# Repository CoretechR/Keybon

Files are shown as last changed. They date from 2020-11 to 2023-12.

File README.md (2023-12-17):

# Keybon - Adaptive Macro Keyboard

Keybon is a macro keyboard with configurable layouts and functions. Integrated into each of its nine tactile buttons is a 0.66” OLED screen. Depending on which app is active on the connected computer, Keybon switches to the suitable key layout thanks to its companion software.

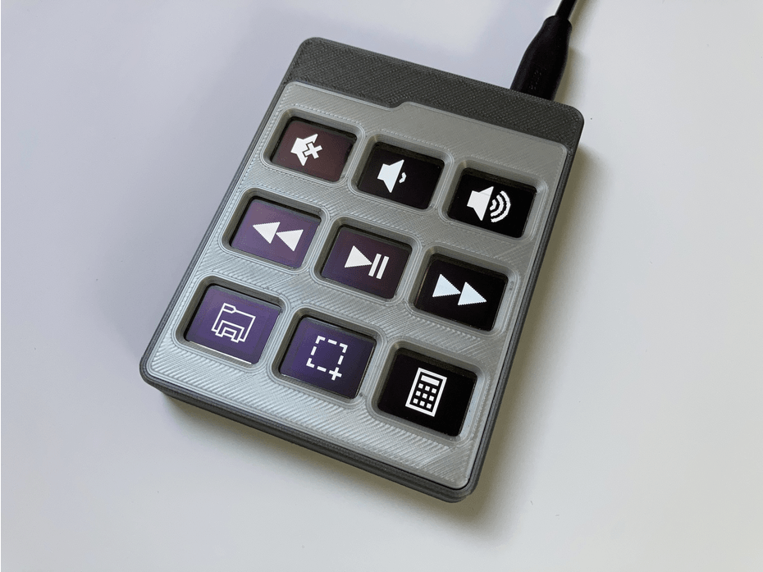
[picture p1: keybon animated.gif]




# Instructions

1.  Download the USB bootloader: https://github.com/rogerclarkmelbourne/STM32duino-bootloader

    Connect a USB-to-Serial adapter to the TX/RX pins of your board. Close the BOOT0 jumper before applying power.
    
    Flash the USB bootloader to the STM32 via the STM32 flasher:  https://www.st.com/en/development-tools/flasher-stm32.html
2.  Install the required Arduino libraries listed in the keybon.ino file

    Important: Adafruit_GFX_Library version 1.7.5 must be installed (dependencies for newer versions are incompatible with the STM32)
    
    Add the following lines to the Adafruit_SSD1306 library (in Arduino\libraries\Adafruit_SSD1306\Adafruit_SSD1306.cpp) 
    
    ```C++
    else if ((WIDTH == 128) && (HEIGHT == 48)) {
    comPins = 0x12;
	  contrast = (vccstate == SSD1306_EXTERNALVCC) ? 0x9F : 0xCF;
    }
    ```
3.  Install STM32 support for the Arduino IDE: https://github.com/rogerclarkmelbourne/Arduino_STM32

    Install the corresponding drivers: https://github.com/rogerclarkmelbourne/Arduino_STM32/tree/master/drivers
4.  Compile and upload the Arduino sketch:



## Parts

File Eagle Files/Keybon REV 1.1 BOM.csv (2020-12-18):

Qty | Value | Device | Package | Parts | LCSC Link
1 |  | USB_C16PIN | USB-C-16P | J2 | https://lcsc.com/product-detail/USB-Connectors_SOFNG-MC-311D_C136423.html
32 | 1.0uF |  | 0603 | C1; C2; C3; C8; C10; C11; C14; C15; C18; C19; C20; C23; C24; C25; C28; C29; C30; C33; C34; C35; C38; C39; C40; C43; C44; C45; C48; C49; C50; C53; C54; C55 | https://lcsc.com/product-detail/Multilayer-Ceramic-Capacitors-MLCC-SMD-SMT_Samsung-Electro-Mechanics-CL10A105MB8NNNC_C307457.html
3 | 10k |  | 0603 | R8; R12; R15 | https://lcsc.com/product-detail/Chip-Resistor-Surface-Mount_10KR-103-5_C144116.html
2 | 18pF |  | 0603 | C6; C7 | https://lcsc.com/product-detail/Multilayer-Ceramic-Capacitors-MLCC-SMD-SMT_Walsin-Tech-Corp-0603N180J500CT_C123538.html
3 | 1k |  | 0603 | R16; R17; R18 | https://lcsc.com/product-detail/Chip-Resistor-Surface-Mount_FH-Guangdong-Fenghua-Advanced-Tech-RS-03K1001FT_C115325.html
1 | 1k5 |  | 0603 | R20 | https://lcsc.com/product-detail/Chip-Resistor-Surface-Mount_1-5KR-152-5_C138275.html
10 | 2.2uF |  | 0603 | C4; C9; C17; C22; C27; C32; C37; C42; C47; C52 | https://lcsc.com/product-detail/Multilayer-Ceramic-Capacitors-MLCC-SMD-SMT_YAGEO-CC0603MRY5V7BB225_C519506.html
2 | 27 |  | 0603 | R13; R14 | https://lcsc.com/product-detail/Chip-Resistor-Surface-Mount_TA-I-Tech-RMS06JT270_C209231.html
9 | 390k |  | 0603 | R1; R2; R4; R5; R6; R7; R9; R10; R11 | https://lcsc.com/product-detail/Chip-Resistor-Surface-Mount_YAGEO-RC0603JR-07390KL_C137633.html
9 | 4.7uF |  | 0603 | C5; C16; C21; C26; C31; C36; C41; C46; C51 | https://lcsc.com/product-detail/Multilayer-Ceramic-Capacitors-MLCC-SMD-SMT_YAGEO-CC0805KKX7R6BB475_C520074.html
2 | 47pF |  | 0603 | C12; C13 | https://lcsc.com/product-detail/Multilayer-Ceramic-Capacitors-MLCC-SMD-SMT_YAGEO-CC0603JRNPO8BN470_C519392.html
2 | 5.1k |  | 0603 | R3; R19 | https://lcsc.com/product-detail/Chip-Resistor-Surface-Mount_RALEC-RTT035101FTP_C103686.html
1 | 500mA | PTCSMD | PTC-1206 | F1 | https://lcsc.com/product-detail/PTC-Resettable-Fuses_Fuzetec-Tech-FSMD025-24-1206-R_C220146.html
1 | 8MHz | CRYSTAL5X3 | CRYSTAL-SMD-5X3 | OSC | https://lcsc.com/product-detail/SMD-Crystal-Resonators_Abracon-LLC-ABM3B-8-000MHZ-10-1-U-T_C276420.html
1 | AP2112K-3.3V | V_REG_LDOSMD | SOT23-5 | U3 | https://lcsc.com/product-detail/Dropout-Regulators-LDO_Diodes-Incorporated_AP2112K-3-3TRG1_Diodes-Incorporated-AP2112K-3-3TRG1_C51118.html
10 | EVQQ | B3FS-1000P | EVQ-Q2_SMALLER | SW1; SW2; SW3; SW4; SW5; SW6; SW7; SW8; SW9; SW10 | https://lcsc.com/product-detail/Tactile-Switches_Omron-Electronics-B3FS-1000P_C271750.html
9 | OLED0.66 | OLED0.66 | OLED-0.66-64X48 | OLED1; OLED2; OLED3; OLED4; OLED5; OLED6; OLED7; OLED8; OLED9 | https://lcsc.com/product-detail/OLED-Displays-Modules_UG-Univision-Semicon-UG-6448KLBEG03_C88334.html
1 | STM32F103C8T6 | STM32F103C8T6 | LQFP48 | UC1 | https://lcsc.com/product-detail/ST-Microelectronics_STMicroelectronics-STM32F103C8T6_C8734.html

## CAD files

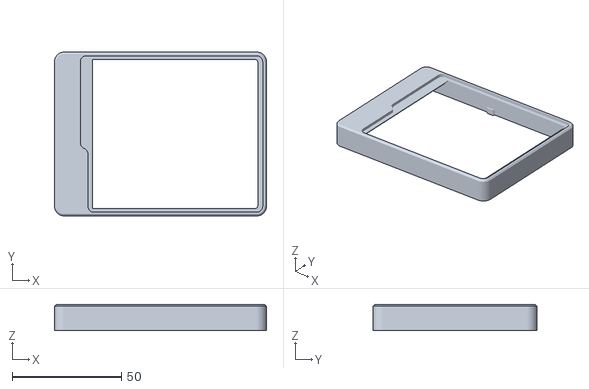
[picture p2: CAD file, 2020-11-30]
CAD Files/Shell.stl
97.0 x 75.0 x 12.0

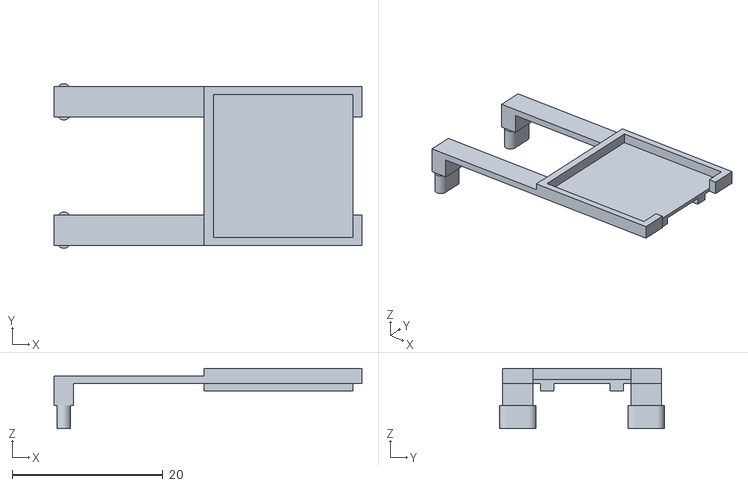
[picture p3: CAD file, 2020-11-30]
CAD Files/button A.stl
40.8 x 21.8 x 8.00

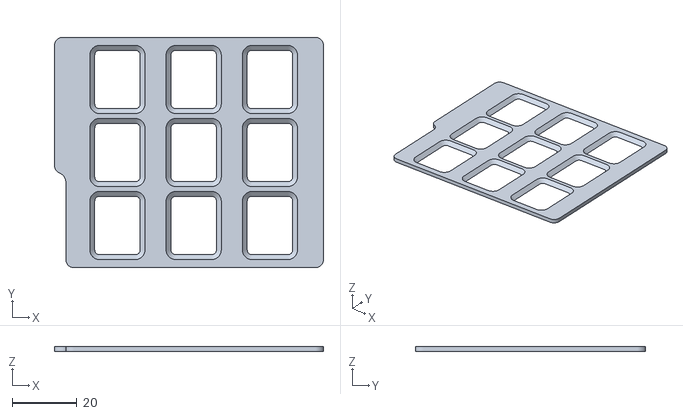
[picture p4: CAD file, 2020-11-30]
CAD Files/Cover Plate.stl
82.9 x 71.0 x 1.50

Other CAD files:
CAD Files/button B.stl

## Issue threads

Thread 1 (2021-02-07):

Unable to build the firmware

r00li, 2021-02-07:
Hi!
I managed to assemble the hardware for this and I am now trying to get the firmware built but I am not having any luck. Can you provide a bit more information on the versions of the libraries that were used? Or maybe even provide a pre-built bin file that can be flashed onto the board?

I've downloaded the latest versions of the Arduino_STM32 that was linked on the hackaday project, I am also using the latest versions of other libraries that are used and I am getting the following errors when I am trying to compile the firmware source:

```WARNING: library JC_Button-2.1.2 claims to run on avr architecture(s) and may be incompatible with your current board which runs on STM32F1 architecture(s).
/Users/roli/Documents/Arduino/libraries/Adafruit_BusIO/Adafruit_I2CDevice.cpp: In member function 'bool Adafruit_I2CDevice::write(const uint8_t*, size_t, bool, const uint8_t*, size_t)':
/Users/roli/Documents/Arduino/libraries/Adafruit_BusIO/Adafruit_I2CDevice.cpp:88:47: error: invalid conversion from 'const uint8_t* {aka const unsigned char*}' to 'uint8* {aka unsigned char*}' [-fpermissive]
     if (_wire->write(prefix_buffer, prefix_len) != prefix_len) {
                                               ^
In file included from /Users/roli/Documents/Arduino/hardware/Arduino_STM32/STM32F1/libraries/Wire/Wire.h:42:0,
                 from /Users/roli/Documents/Arduino/libraries/Adafruit_BusIO/Adafruit_I2CDevice.h:1,
                 from /Users/roli/Documents/Arduino/libraries/Adafruit_BusIO/Adafruit_I2CDevice.cpp:1:
/Users/roli/Documents/Arduino/hardware/Arduino_STM32/STM32F1/libraries/Wire/utility/WireBase.h:123:12: note:   initializing argument 1 of 'size_t WireBase::write(uint8*, int)'
     size_t write(uint8*, int);
            ^~~~~
/Users/roli/Documents/Arduino/libraries/Adafruit_BusIO/Adafruit_I2CDevice.cpp:97:31: error: invalid conversion from 'const uint8_t* {aka const unsigned char*}' to 'uint8* {aka unsigned char*}' [-fpermissive]
   if (_wire->write(buffer, len) != len) {
                               ^
In file included from /Users/roli/Documents/Arduino/hardware/Arduino_STM32/STM32F1/libraries/Wire/Wire.h:42:0,
                 from /Users/roli/Documents/Arduino/libraries/Adafruit_BusIO/Adafruit_I2CDevice.h:1,
                 from /Users/roli/Documents/Arduino/libraries/Adafruit_BusIO/Adafruit_I2CDevice.cpp:1:
/Users/roli/Documents/Arduino/hardware/Arduino_STM32/STM32F1/libraries/Wire/utility/WireBase.h:123:12: note:   initializing argument 1 of 'size_t WireBase::write(uint8*, int)'
     size_t write(uint8*, int);
            ^~~~~
Multiple libraries were found for "Wire.h"
 Used: /Users/roli/Documents/Arduino/hardware/Arduino_STM32/STM32F1/libraries/Wire
 Not used: /Users/roli/Documents/Arduino/hardware/Arduino_STM32/STM32F1/libraries/WireSlave
Multiple libraries were found for "USBComposite.h"
 Used: /Users/roli/Documents/Arduino/hardware/Arduino_STM32/STM32F1/libraries/USBComposite
 Not used: /Users/roli/Documents/Arduino/libraries/USBComposite_stm32f1-0.99
exit status 1
Error compiling for board Generic STM32F103C6/fake STM32F103C8.
```

CoretechR, 2021-02-07:
Hi! Looks like these errors are due to using the Adafruit_BusIO library. I just noticed that this library is now a dependency for the Adafruit GFX lib. I am still using Adafruit GFX version 1.7.5 which does not have this dependency.
In any case I've added a binary file for the STM32F103C8: [keybon.generic_stm32f103c.zip](https://github.com/CoretechR/Keybon/files/5939469/keybon.generic_stm32f103c.zip)

r00li, 2021-02-07:
Awesome. Thanks. Yes, reverting to 1.7.5 did enable me to build the project.

I am still having issues uploading it though. I've uploaded the bootloader (generic_boot20_pc13.bin) as suggested but the thing still doesn't show up on my computer when I plug in the USB. Just to double check - should any of the BOOT0/BOOT1 be shorted while trying to upload a new binary - after the initial bootloader is uploaded that is?

CoretechR, 2021-02-07:
BOOT1/BOOT0 should be left open (connected to GND via resistors).
With the bootloader the STM32 should show up as a virtual COM port.
What hardware are you using - a bluepill board or the keyboard from this project?
The bluepills are notorious for having a hardware error that causes USB problems: http://amitesh-singh.github.io/stm32/2017/05/27/Overcoming-wrong-pullup-in-blue-pill.html

r00li, 2021-02-07:
Well this is fun. Mine doesn't show up at all.

I am using the board/components from this project. As always could be an issue with my soldering somewhere.

CoretechR, 2021-02-07:
OK, cool, soldering these USB-C connectors can be tricky. Try double checking the connections and maybe use a multimeter for continuity testing. We're going to get this to work! 😄

r00li, 2021-02-07:
Hmmm. I've tried plugging it into a windows machine since that is usually more lenient towards weird USB devices. And windows does actually detect it. Although I get an "unknown device" and if I check it on the control panel I get: "device descriptor request failed".

CoretechR, 2021-02-07:
Did you install the drivers from the Arduino_STM32 folder? Maybe a reinstallation can fix it.

r00li, 2021-02-07:
Based on the error and the fact that it is not recognized by my Mac at all I would guess that it is either some sort of hardware or firmware issue. The fact that I now can't even re-install bootloader through serial has me worried.

CoretechR, 2021-02-07:
That's strange. Flashing the bootloader via serial should work no matter which sketch is running.
Are you sure the soldering connections are good? Can you maybe post a picture?

r00li, 2021-02-07:
Could be that I was just having some issues shorting the BOOT0 pad. But since this seems to be working ok now I will treat this as a success.

Here is a picture though. If you maybe can see something on the board that is out of place.

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

CoretechR, 2021-02-07:
There are not many components involved in the USB interface. Your soldering looks very clean. The only thing I can't verify is the crystal and the right side of the STM32. Maybe the D+ or D- pins could use some more solder. Apart from that I have no idea.

r00li, 2021-02-07:
Found the issue:
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

The cap and resistors that are circled needed to be swapped. Apparently the designators are placed in a funny position. The board is now getting recognized as a Maple 003.

I am still getting issues uploading the FW though:
```WARNING: library JC_Button-2.1.2 claims to run on avr architecture(s) and may be incompatible with your current board which runs on STM32F1 architecture(s).
Sketch uses 40640 bytes (62%) of program storage space. Maximum is 65536 bytes.
Global variables use 8104 bytes (39%) of dynamic memory, leaving 12376 bytes for local variables. Maximum is 20480 bytes.
/Users/roli/Documents/Arduino/hardware/Arduino_STM32/tools/macosx/maple_upload cu.usbserial-00000000 2 1EAF:0003 /var/folders/96/d_b8vx8178l1twdc7zpmv5400000gn/T/arduino_build_749183/keybon.ino.bin /Applications/Arduino.app/Contents/Java
Failed to open serial device.
dfu-util: Invalid DFU suffix signature
dfu-util: A valid DFU suffix will be required in a future dfu-util release!!!
dfu-util: Invalid dfuse address: /Applications/Arduino.app/Contents/Java
An error occurred while uploading the sketch

dfu-util 0.8

Copyright 2005-2009 Weston Schmidt, Harald Welte and OpenMoko Inc.
Copyright 2010-2014 Tormod Volden and Stefan Schmidt
This program is Free Software and has ABSOLUTELY NO WARRANTY
Please report bugs to http://sourceforge.net/p/dfu-util/tickets/

Opening DFU capable USB device...
ID 1eaf:0003
Run-time device DFU version 0110
Claiming USB DFU Interface...
Setting Alternate Setting #2 ...
Determining device status: state = dfuIDLE, status = 0
dfuIDLE, continuing
DFU mode device DFU version 0110
Device returned transfer size 1024
```

CoretechR, 2021-02-07:
Awesome! Sorry for the bad text placement! Does the same error occur on windows?

r00li, 2021-02-07:
Not sure. I will try tomorrow. Can you maybe just check the settings in arduino for me, just so I can confirm that I have everything selected correctly?

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

CoretechR, 2021-02-07:
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
Yes, that looks exactly like what I'm using.

r00li, 2021-02-08:
Almost there. Managed to get it to build on windows (looks like the dfu util version included in arduino_stm32 is a bit too old for newer versions of mac os).

Now on to the next problem...
Can you maybe tell me which version of the ssd1306 library you are using? Just so I can check that it's not that.

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

CoretechR, 2021-02-08:
I know what's causing this. Actually I forgot about this until now - The Adafruit_SSD1306 library does not officially support this display resolution. I had to add a few lines to the Adafruit_SSD1306.cpp: [Adafruit_SSD1306.zip](https://github.com/CoretechR/Keybon/files/5944739/Adafruit_SSD1306.zip)
These are the changes:
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
Notice that the width is 128px while the screen only has 64. I had weird effects when using the actual resolution so this was a workaround. A side effect is that everything has to be shifted 32px to the right.

r00li, 2021-02-08:
Yep, that was it. Thank you for the help! Got it working now.

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

A few of the buttons didn't work because my pcb cleaner leaves weird sticky residue on the board and it messes with the switches. But soaking the thing in massive amounts of contact cleaner solved that as well. Now onto my next challenge of actually building an app that will work with this on mac os.

CoretechR, 2021-02-08:
Cool! Thanks for posting the picture! I will add some more instructions to the projects so the next person building this will have a smoother experience.
May I ask where you bought the OLED screens from? LCSC is out of stock and I'm thinking of assembling another keyboard.

r00li, 2021-02-08:
Awesome!

I bought them on AliExpress: https://www.aliexpress.com/item/32835519387.html?spm=a2g0s.9042311.0.0.2a274c4dEsgzVu
They are cheaper than the ones from LCSC as well which is nice.

LinBingKe, 2021-03-02:
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

Closed 2021-02-08.

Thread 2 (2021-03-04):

Button Library

koogar, 2021-03-04:
I had to rename the button library based on your link
#include <JC_Button.h>  for it to compile.

Great project BTW :)

gromain, 2021-03-07:
Also, you should be careful with the version of the library you used. The v2.0.0 release introduced a breaking change in the code https://github.com/JChristensen/JC_Button/releases/tag/2.0.0 .
If you don't want to do the following change, the latest version to use the original `Button.h` and its constructor is v1.0.1 .
Basically, you have to change the order of the parameters in the constructor of the Button.

It now looks like this:
```
Button button01(SW01, 5, true, true); //pin, debounce, pullup, invert
Button button02(SW02, 5, true, true); //pin, debounce, pullup, invert
Button button03(SW03, 5, true, true); //pin, debounce, pullup, invert
Button button04(SW04, 5, true, true); //pin, debounce, pullup, invert
Button button05(SW05, 5, true, true); //pin, debounce, pullup, invert
Button button06(SW06, 5, true, true); //pin, debounce, pullup, invert
Button button07(SW07, 5, true, true); //pin, debounce, pullup, invert
Button button08(SW08, 5, true, true); //pin, debounce, pullup, invert
Button button09(SW09, 5, true, true); //pin, debounce, pullup, invert
```

gromain, 2021-03-07:
Also, you can add the following in `setup()`:
```
  button01.begin();
  button02.begin();
  button03.begin();
  button04.begin();
  button05.begin();
  button06.begin();
  button07.begin();
  button08.begin();
  button09.begin();
```

koogar, 2021-03-08:
Thanks for the reply.

I just wanted to point it out as most people will just download whatever version is on the Github, unless told.

Cheers

Rupert

Closed 2021-03-08.

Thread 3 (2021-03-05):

CAD design source files

gromain, 2021-03-05:
Hey,

I've designed a 12 button version of Keybon, and I wanted to know if you could share the source files for the CAD design, so I can modify it to integrate the 3 additional button.

Of course, I'll share my changes in a fork!

Cheers,
Romain

gromain, 2021-03-06:
Thanks a lot!

Closed 2021-03-06.

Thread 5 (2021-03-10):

Gerber Files

asutrem, 2021-03-10:
When exporting the gerber files, the holes for the USB C port are not generated. How do I go about fixing this?

CoretechR, 2021-03-11:
I am not an expert on EAGLE cam jobs. I successfully generated files using the settings that JLCPCB provides and the slots came out fine. The slots might not show up on the drill layer, there should be an additional layer for millings.

asutrem, 2021-03-11:
Ok, I will check out the steps on jlcpcb when I order. thank you!

Closed 2021-03-11.

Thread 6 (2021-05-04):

BOM Part Package Difference

gren236, 2021-05-04:
Hello! First of all - thank you for an amazing project!
I'm going to build one, but during the BOM list checking I've stumbled upon the difference of "C1,C2,C3" capacitors between the EAGLE board schema items list and the actual BOM inside this repo. `Keybon REV 1.1 BOM.csv` file has `0603` package defined for this capacitors, but in EAGLE schema they have `0805` package. What should I trust?

CoretechR, 2021-05-04:
Hi, I usually only use 0603 components in my designs. But a few footprints are copy/pasted from other projects so some 0805 footprints might end up in the pcb. While I prefer 0603, these footprints can be populated with both 0603 and 0805.

gren236, 2021-05-04:
Great, thanks! Gonna stick to 0805 then

Closed 2021-05-04.

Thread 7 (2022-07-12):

Can't flash bootloader keybon.generic_stm32f103c

4gordi, 2022-07-12:
Hi, everyone. I finished one keybon, and i have some problem. Firstly - after flash bootloader with keybon.generic_stm32f103c, i can't connect keybon to pc (windows 10), becouse error message usb device not recognized. But if i flash bootloader with generic_boot20_pc13 from rogerclarkmelbourne and remove the jumper boot0, keybon defined by the system as maple serial and i can flash arduino-hardware.
secondly - after flashing keybon.ino keyboard work fine, more precisely buttons, but screen work only second. Do you help me?

CoretechR, 2022-07-12:
Hi, "generic_boot20_pc13" is the right bootloader. I should include that in the description.
So only one of the 9 screens work? Have you double checked your solder connections? Can you maybe post a picture?
It is easy to short-circuit the flex connector if you are not careful.

4gordi, 2022-07-12:
Yes, second screen show picture, another screens don’t work. I can see short-circuit on x-ray machine

4gordi, 2022-07-12:
Maybe it’s problem becouse of i using wrong version of arduino ide or versions of libraries? I know button.h is outdated now.

4gordi, 2022-07-13:
Adafruit_GFX_Library i’m use 1.7.5. When compiling, it displays an error related to button.h

4gordi, 2022-07-13:
![Uploading AAF0FF3B-0538-4930-ACB2-37BD0D4E2F0A.jpeg…]()

4gordi, 2022-07-13:
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

CoretechR, 2022-07-13:
Those solder joints look perfect. An X-Ray is really a helpful tool.
I would try to reduce the code to the minimum. Just initialise one display, make it solid white and then start with the second one that already works. Then you can change the code to another display and see if that does anything. This way you can also rule out any other library dependencies as you will only need the display libraries.

4gordi, 2022-07-13:
Thanx, i found my problem - bad PCB( Initially there was a problem with a 3.3 short to gnd, an underetched circuit board, and now there was no miso signal on all other screens except the second one. Sorry, before additional wire laying on miso, work perfect)

CoretechR, 2022-07-13:
That's great! Thanks for posting the photos. I will include the new button library in the description. It has been added to the Arduino ide for a long time, so there is no need to get it from GitHub anymore.

Closed 2022-07-14.

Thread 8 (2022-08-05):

dfu mode

F1hone, 2022-08-05:
Hello,
I like your keybon very much, I made one too, but I don't know how to use tx/rx to burn my board,
For bl, I chose to use stlink, I flew dio and clk on the board, which allowed me to flash the bootloader smoothly, and it could be recognized by the computer, but I don't know how to burn the program in the arduino into it
I don't know how to get the board into dfu mode

F1hone, 2022-08-05:
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

F1hone, 2022-08-05:
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

F1hone, 2022-08-05:
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

CoretechR, 2022-08-05:
Hi, are you sure the correct driver is installed? The board should show up as a serial port in the device manager.
You might also try to flash the bootloader again.
I am not sure if this could be hardware related. If there is a bad solder joint on the USB interface, the device should not show up at all. But you could check that, too, just to be safe.

F1hone, 2022-08-05:
I don't know what kind of driver I should use. After I flashed generic_boot20_pc13.bin, the maple 003 is displayed when I use usb to connect to the computer. I am using CH340. What driver should I use?
I just need to connect the rx/tx of the board to the rx/tx of the ch340. Is the power supply of the board borne by the typec?
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

F1hone, 2022-08-05:
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
yes
I successfully used the software you recommended with ch340 to flash into bl, but the cooperation with arduino is still not very good

CoretechR, 2022-08-05:
What exactly do you use the ch340 for? After the bootloader is installed, you can program the board via the USB-C connector. You need the serial connector only for flashing the bootloader.

F1hone, 2022-08-05:
。。。。。

F1hone, 2022-08-05:
But my arduino still can't upload
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
But my arduino still can't upload
The board is not recognized as a serial port, but maple 003

CoretechR, 2022-08-05:
Have you installed the drivers from here:
https://github.com/rogerclarkmelbourne/Arduino_STM32/tree/master/drivers

F1hone, 2022-08-05:
i have run [wdi-simple.exe] once,
But now I think it should be a driver problem, so I run almost everything in there

CoretechR, 2022-08-05:
Try running the .bat files. If it does not show up as a serial port its definitely a driver problem.

F1hone, 2022-08-05:
yes
i made it
thank you very much

CoretechR, 2022-08-05:
That's great! Glad I could help.

F1hone, 2022-08-05:
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

F1hone, 2022-08-05:
Thank you so much for your help, I couldn't have done it without you
Then, I want to ask, how should I use the software, how should the hotkey be bound to the program and the process, I hardly know anything about it

CoretechR, 2022-08-05:
Your PCB looks really nice!
The app works like this: You select one of the layouts from the drop down list. Then you drag/drop images to the buttons. Black/white icons work best.
Then you can insert a command that runs when a button is pressed. The code works like the sendkeys method: https://docs.microsoft.com/en-us/office/vba/language/reference/user-interface-help/sendkeys-statement
You can read more about the app here:
https://hackaday.io/project/176239-keybon-adaptive-macro-keyboard/log/186859-companion-app

F1hone, 2022-08-05:
Thanks a lot, I'll look into it

mayjack0312, 2023-11-20:
> 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

Hello, what kind of screen do you use?
I think the [UG(Univision Semicon) UG-6448KLBEG03](https://www.lcsc.com/product-detail/OLED-Displays-Modules_UG-Univision-Semicon-UG-6448KLBEG03_C88334.html) screen is a bit too expensive
Can you recommend any cheaper alternative screens?

Closed 2025-01-29.

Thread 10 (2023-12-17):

Something went wrong, please help

mayjack0312, 2023-12-17:
The bootloader has been flashed normally and the device has been recognized, but when programming the program, the output is:
```
WARNING: library JC_Button claims to run on avr architecture(s) and may be incompatible with your current board which runs on STM32F1 architecture(s).
Sketch uses 36364 bytes (55%) of program storage space. Maximum is 65536 bytes.
Global variables use 6048 bytes (29%) of dynamic memory, leaving 14432 bytes for local variables. Maximum is 20480 bytes.
```
Moreover, the screen does not light up after programming, and the button settings do not respond.
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

CoretechR, 2023-12-17:
Hi, there are a lot of weird dependencies and old libraries that this project uses. So it can be a little tricky to set up.
I just added a binary file that you can try to flash to your board:
https://github.com/CoretechR/Keybon/blob/main/keybon/keybon.ino.generic_stm32f103c.bin

mayjack0312, 2023-12-17:
> Hi, there are a lot of weird dependencies and old libraries that this project uses. So it can be a little tricky to set up. I just added a binary file that you can try to flash to your board: https://github.com/CoretechR/Keybon/blob/main/keybon/keybon.ino.generic_stm32f103c.bin

I don’t know the technology well, so I hope you can help me. This project is really great. Thank you again for the firmware.

mayjack0312, 2023-12-17:
> > Hi, there are a lot of weird dependencies and old libraries that this project uses. So it can be a little tricky to set up. I just added a binary file that you can try to flash to your board: https://github.com/CoretechR/Keybon/blob/main/keybon/keybon.ino.generic_stm32f103c.bin
>
> I don’t know the technology well, so I hope you can help me. This project is really great. Thank you again for the firmware.

Please help me, it seems like I’ve fallen over again o(╥﹏╥)o
This time after flashing the firmware, the device can’t even read it.
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

CoretechR, 2023-12-17:
Did you manage to flash the binary file?
In my experience, when Windows does not recognize the device, it was usually a hardware problem. Maybe you have a short on the PCB. You can also try to flash the bootloader again an see if that helps.

mayjack0312, 2023-12-17:
> 您是否成功刷新了二进制文件？ 根据我的经验，当 Windows 无法识别该设备时，通常是硬件问题。可能是你的PCB短路了。您还可以尝试再次刷新引导加载程序，看看是否有帮助。

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

mayjack0312, 2023-12-17:
Then I try to flash the boot now and it can’t be flashed (the flash loader tool is quite mysterious)
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

CoretechR, 2023-12-17:
Yes, the flash loader does not always work on the first try.
But if it does not work at all, I suspect a hardware issue. Please check your PCB, maybe there is something wrong with the wiring.

mayjack0312, 2023-12-17:
> 是的，闪存加载程序并不总是能在第一次尝试时工作。 但如果根本不起作用，我怀疑是硬件问题。请检查你的PCB，可能是接线有问题。
Thank you for your patient answer. I basically spent all night working on the burning problem today.
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
I'm trying to use STM32CubeProgrammer directly for burning. So far, everything is good (I hope I can succeed this time)

mayjack0312, 2023-12-17:
This is the error log when uploading to arduino
[hs_err_pid28812.log](https://github.com/CoretechR/Keybon/files/13697397/hs_err_pid28812.log)

CoretechR, 2023-12-17:
I have not worked with STM32CubeProgrammer before and don't know what is causing this error, sorry.

mayjack0312, 2023-12-17:
> I have not worked with STM32CubeProgrammer before and don't know what is causing this error, sorry.

I searched online again and checked. The upload did not fail. The STM32CubeProgrammer burning should have been successful, but the screen did not light up and the function keys seemed to have no effect.

Closed 2023-12-18.

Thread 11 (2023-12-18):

Please give me some answers these days. After struggling all night, I successfully lit it up ❥(^_-)

mayjack0312, 2023-12-18:
# Prompt before burning：
```
Sketch uses 36364 bytes (55%) of program storage space. Maximum is 65536 bytes.
Global variables use 6048 bytes (29%) of dynamic memory, leaving 14432 bytes for local variables. Maximum is 20480 bytes.
maple_loader v0.1
Resetting to bootloader via DTR pulse
Searching for DFU device [1EAF:0003]...
Reset via USB Serial Failed! Did you select the right serial port?
Assuming the board is in perpetual bootloader mode and continuing to attempt dfu programming...

Found it!

Opening USB Device 0x1eaf:0x0003...
Found Runtime: [0x1eaf:0x0003] devnum=1, cfg=0, intf=0, alt=2, name="STM32duino bootloader v1.0  Upload to Flash 0x8002000"
Setting Configuration 1...
Claiming USB DFU Interface...
Setting Alternate Setting ...
Determining device status: state = dfuIDLE, status = 0
dfuIDLE, continuing
Transfer Size = 0x0400
bytes_per_hash=727
Starting download: [##################################################] finished!
error resetting after download: usb_reset: could not reset device, win error: ָ�������ڵ��豸��

state(8) = dfuMANIFEST-WAIT-RESET, status(0) = No error condition is present
Done!
Resetting USB to switch back to runtime mode
timeout waiting for COM5 serial
```
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

# Then it prompts that the device installation is successful
# Then the screen lights up normally and the host computer runs normally.
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

  **The measured screen used the 4.5 yuan ssd1315 driver screen and there was no problem.**

CoretechR, 2023-12-18:
Awesome! Do you know what the error was or what you are now doing differently?

mayjack0312, 2023-12-18:
> Awesome! Do you know what the error was or what you are now doing differently?

The problems encountered are as follows：
1. Burning, flash loader metaphysics is invalid, I don’t know why
2. Compilation, various libraries report errors

CoretechR, 2023-12-18:
Here is the documentation for this kind of keyboard command: https://learn.microsoft.com/en-us/dotnet/api/system.windows.forms.sendkeys.send?view=windowsdesktop-8.0

mayjack0312, 2023-12-18:
> Here is the documentation for this kind of keyboard command: https://learn.microsoft.com/en-us/dotnet/api/system.windows.forms.sendkeys.send?view=windowsdesktop-8.0

Okay, thank you for the feeding tutorial, I will study it first

Closed 2025-01-29.

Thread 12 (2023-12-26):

for keybon companion app, be able to disable switch layouts when window focus changes

b4wii, 2023-12-26:
trying to use this as a custom streamdeck, to be used with obs. but as the current iteration of keybon, there is no way to change the default screen, except changing the sketch in the Arduino ide, and there is no way to have the companion not switch layouts when the focus of the current window changes.

would be nice to have a toggle function to keep a certain layout active full-time, regardless of what window is active.
I'd edit the companion app myself, but I do not know enough c# to be able to add this functionality.

I realize that this is not a use for what keybon was originally intended for, but I think it could be used like a stream deck, just without all the fancy features of a stream deck. implemented.
I just would like to be able to have it send a few certain button presses for hotkeys for OBS Studio, but with the current version of keybon this is pretty much impossible without doing some major coding on my part.

CoretechR, 2023-12-27:
That's a good idea. I never really thought about that but it would make sense.
Have you already built a working Keybon?

b4wii, 2023-12-27:
Yes. And when trying to set up companion it was kinda frustrating having it switch layouts all the time.

CoretechR, 2023-12-28:
[keybon companion b4wii.zip](https://github.com/CoretechR/Keybon/files/13782160/keybon.companion.b4wii.zip)
I made some quick changes to allow modifying the default page. Could you try and see if that works for you?

b4wii, 2023-12-28:
okay, while it does let me make changes on the default screen, I don't seem to be able to make it function with the F13-F24 keys, even though sendkeys supports those keys. and that is what my hotkeys are set up for in my different programs.

CoretechR, 2023-12-28:
That's strange. The function keys seem to work for me using {F5} for example. Can you try with this version again, please?
[keybon companion b4wii.zip](https://github.com/CoretechR/Keybon/files/13787915/keybon.companion.b4wii.zip)

b4wii, 2023-12-28:
okay, in testing, it seems to stop at F16. anything beyond for the f17-f24 does not work.

https://learn.microsoft.com/en-us/previous-versions/troubleshoot/winautomation/product-documentation/best-practices/valid-key-codes-for-the-send-keys-action

supposedly these are supported according to these tables.  unless I am reading wrongly.

CoretechR, 2023-12-29:
Oh, I thought all the function keys don't work. I must have misread that. Depending on where you look, the documentation lists F16 as the last working function key with the sendkeys method:
https://learn.microsoft.com/en-us/dotnet/api/system.windows.forms.sendkeys.send?view=windowsdesktop-8.0

b4wii, 2023-12-29:
That could be the case and makes sense. Kinda disappointed that send keys only seems to support up to f16.

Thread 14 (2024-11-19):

CPL File

slimline33, 2024-11-19:
Hi Max,

I hope this message finds you well! I just discovered your project today, and I must say, it’s absolutely fantastic—great work!

Would it be possible for you to provide a CPL file for JLCPCB? This would allow us to have most of the components pre-assembled, saving time and effort.

Thank you in advance for your help, and please let me know if you need any additional details!

Best regards,

Christoph

slimline33, 2024-11-21:
thanks! That will help!

slimline33, 2024-11-21:
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

"Yes, definitely double-check! 😊 The F1 fuse selected by JLCPCB isn't the correct part, but it's no problem—I can solder it by hand. I paid €65 for 5 boards, including shipping and taxes, without the OLED.

I think the price is really fair."

Closed 2024-11-21.

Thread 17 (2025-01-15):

Were to finde the needed include-files?

Michri, 2025-01-15:
Hello,
I tried to get the STM32 code up and running, but I already struggle with getting it compiled (Arduino IDE).

There are two includes mentioned, where I am not sure, where to find them:
`#include <USBComposite.h>
#include <Button.h> // https://github.com/JChristensen/Button`

When checking https://github.com/JChristensen/Button, there is file listed in the src-folder, called "JC_Button.h". Is it this one? So I just need to rename it?

But where might I find the USBComposite.h?

Thanks a lot for your help.

CoretechR, 2025-01-15:
Hi, are you using the right core for the STM32? That should be https://github.com/rogerclarkmelbourne/Arduino_STM32 which includes a USBComposite.h.
And for the button library, I found this folder in my Arduino library directory:
[Button.zip](https://github.com/user-attachments/files/18428223/Button.zip)
The library must have been renamed to JC_Button later and I was using an ancient version.

Michri, 2025-01-15:
Hello,

thanks a lot for the Button.zip. :)

I still struggle with getting the code up and running - right now I just try to get the code compiled only, to take step by step the next steps. I have to admit, that I am neither an arduino IDE nor an C-expert. :(
I have installed Arduino IDE (2.3.4). Then I downloaded the Arduino_STM32-master.zip from [https://github.com/rogerclarkmelbourne/Arduino_STM32](url) and copied the content from within the zip-file to the Documents\Arduino\hardware folder of the user (Windows 11). Here I renamed the folder from Arduino_STM32-master to Arduino_STM32.
Documents\Arduino\libraries is containing: Adafruit_BusIO, Adafruit_GFX_Library, Adafruit_SSD1306, the Button folder you provided.

When I now start compiling, I get this error still:
_G:\\keybon\keybon.ino:1:10: fatal error: USBComposite.h: No such file or directory
    1 | #include <USBComposite.h>
      |          ^~~~~~~~~~~~~~~~
compilation terminated.
exit status 1

Compilation error: USBComposite.h: No such file or directory_

Do I need to register the files somewhere? Or is it the wrong place? Or do I just need to place an extract of the Arduino_STM32- content?

Really looking forward to your help.
Thanks a lot.

CoretechR, 2025-01-15:
OK, I can try to compile it on the weekend. It's been a while since I programmed the STM32.
The folder structure should be Documents/Arduino/hardware/Arduino_STM32/drivers, tools, etc...
And are you sure you selected the right device from the board menu?

Michri, 2025-01-16:
Oh, maybe I have chosen the wrong device. I selected "Generic STM32F1 series" from "STM32 MPU based boards". Now, when selecting from "STM32F1  Boards (Arduino_STM32) (in Sketchbook), I have set these settings:
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

When now compiling, I get another issue:
_exec: "/bin/arm-none-eabi-g++": executable file not found in %PATH%
Compilation error: exec: "/bin/arm-none-eabi-g++": executable file not found in %PATH%_

BTW: What to be done with the "STM32duino-bootloader", after downloading? Where does it need to be stored?

Michri, 2025-01-16:
Wow, there were a lot of things I had to fix:
As I am using Windows 11, and Arduino IDE 2.3.4, I had to install the Java Runtime (32bit) as well.
I reinstalled the STM32 driver again and then I was able to compile the code and send it to the STM32 :)

It seems to work now. The STM32 is identified as keyboard (right now I am using for testing a BluePill Development board with STM32F103C8T6). When pulling the a pin to low, the related key is sent to the computer. All keystrokes define in the STM32 code seem to work. I do not have the displays in place yet, so this part need to wait some more time.

When using the Windows programm (keybon companion), the com-port is identified correctly, but when defining anothe rlayout, still the default key-strokes are processed (key-strokes as coded in the STM.
Any idea?

CoretechR, 2025-01-16:
I don't see why the bluepill should work differently from the keybon board. Have you tried the compiled exe from GitHub?

Michri, 2025-01-16:
I tried, but Windows 11 is blocking it. It cannot be executed (security warning). I need to find out how to disable the warning.

Michri, 2025-01-17:
When now testing the compiled exe you shared on github, I still have the same issue: Default only is working.

When now starting via Debug-mode (Visual Studio 2022 - 64bit), __serialPort._ is causing issues:
_Ausnahme ausgelöst: "System.InvalidOperationException" in System.dll
Ein Ausnahmefehler des Typs "System.InvalidOperationException" ist in System.dll aufgetreten.
Der Anschluss ist geschlossen.
Das Programm "[2748] keybon companion.exe" wurde mit Code 4294967295 (0xffffffff) beendet._
Seems like the serial port isn't connected correctly.

I have only one COM-port listed in device-manager: COM5. This is shown in the app as well:
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

When debugging, the app always trys to go via COM14:

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

And then the system is skipping this part:

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

When just hard-coding the COM-port for test-purposes, it seems to work:

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

As I am not a C#-expert, I wonder about how to fix this.
Any suggestions about what to do?

CoretechR, 2025-01-18:
Sorry, I missed your edit. Interesting find, maybe I never noticed this because my PC usually has an unused COM1.
COM14 is the default port (portName) that I must have used for testing. The port is actually set via the dropdown here:
```
 private void comboBox2_SelectionChangeCommitted(object sender, EventArgs e)
        {
            _serialPort.Close();
            _serialPort.PortName = comboBox2.SelectedItem.ToString();
            try
            {
                _serialPort.Open();
            }
            catch { }            
        }
```
At some point, the portName string should be overwritten by the settings, because the program remembers the COM port and screen layout. But it's been a few years and that is my only C# project so far. :)

Michri, 2025-01-19:
No worries.
Quite impressive, that this was your first and only C# program 👍
I have never done any coding in C# so far, but as your project is so interested, I tried to dig a little into it.
I did some adjustments in the version I downloaded:
 - alphabetical sorting of items in the list-boxes (showing all and the assigned programs)
 - assigning the COM port again, chosen last time
 - adding '-' to the COM-port and list it as default, when starting first time

I just noticed in the "Pull requests" section, that slimline33 did some enhancements as well. Are these adjustments part of the code presented in GitHub already?
Is there a difference in the code provided in this code-section https://github.com/CoretechR/Keybon compared to https://github.com/CoretechR/Keybon/releases/tag/1.0 ?

CoretechR, 2025-01-20:
Oh no, I forgot about the pull request 😱
I could not get it to run last month but it seems like slimline33 made some updates.
This should definitely be included in the main branch.
You can of course create a pull request with your changes, too.

Michri, 2025-01-20:
I will do my best, as I am new about this as well.
Let me know, when changes of slimline33 have been tested and are working fine. Then I will compare it with my adjustments and add my changes.

Michri, 2025-01-27:
How are things going. Has the code been updated?

I just noticed something different while testing:
For me it looks like the display is updating the content(icons) twice, when switching to another Windows app. I haven't found yet the code snippet, where the update to the STM32 is being triggered, when switching to another Windows app. Can anybody help?

user45876, 2025-01-28:
I just wanted to chime in, having just built my first keybon (with help, though) - the companion app does not work for me as well, it seems to be unable to communicate with they keybon. The serial port is COM24 in that case and it is connected, but the companion app is giving me this:

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

Thanks all!

user45876, 2025-01-28:
I have quickly hacked the prusa slicer icon sidebar into fitting BMPs.

[prusa_icons_keybon.zip](https://github.com/user-attachments/files/18576697/prusa_icons_keybon.zip)

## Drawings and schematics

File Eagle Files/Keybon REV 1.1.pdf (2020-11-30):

# GND EVQQ

STM32F103 | OLED

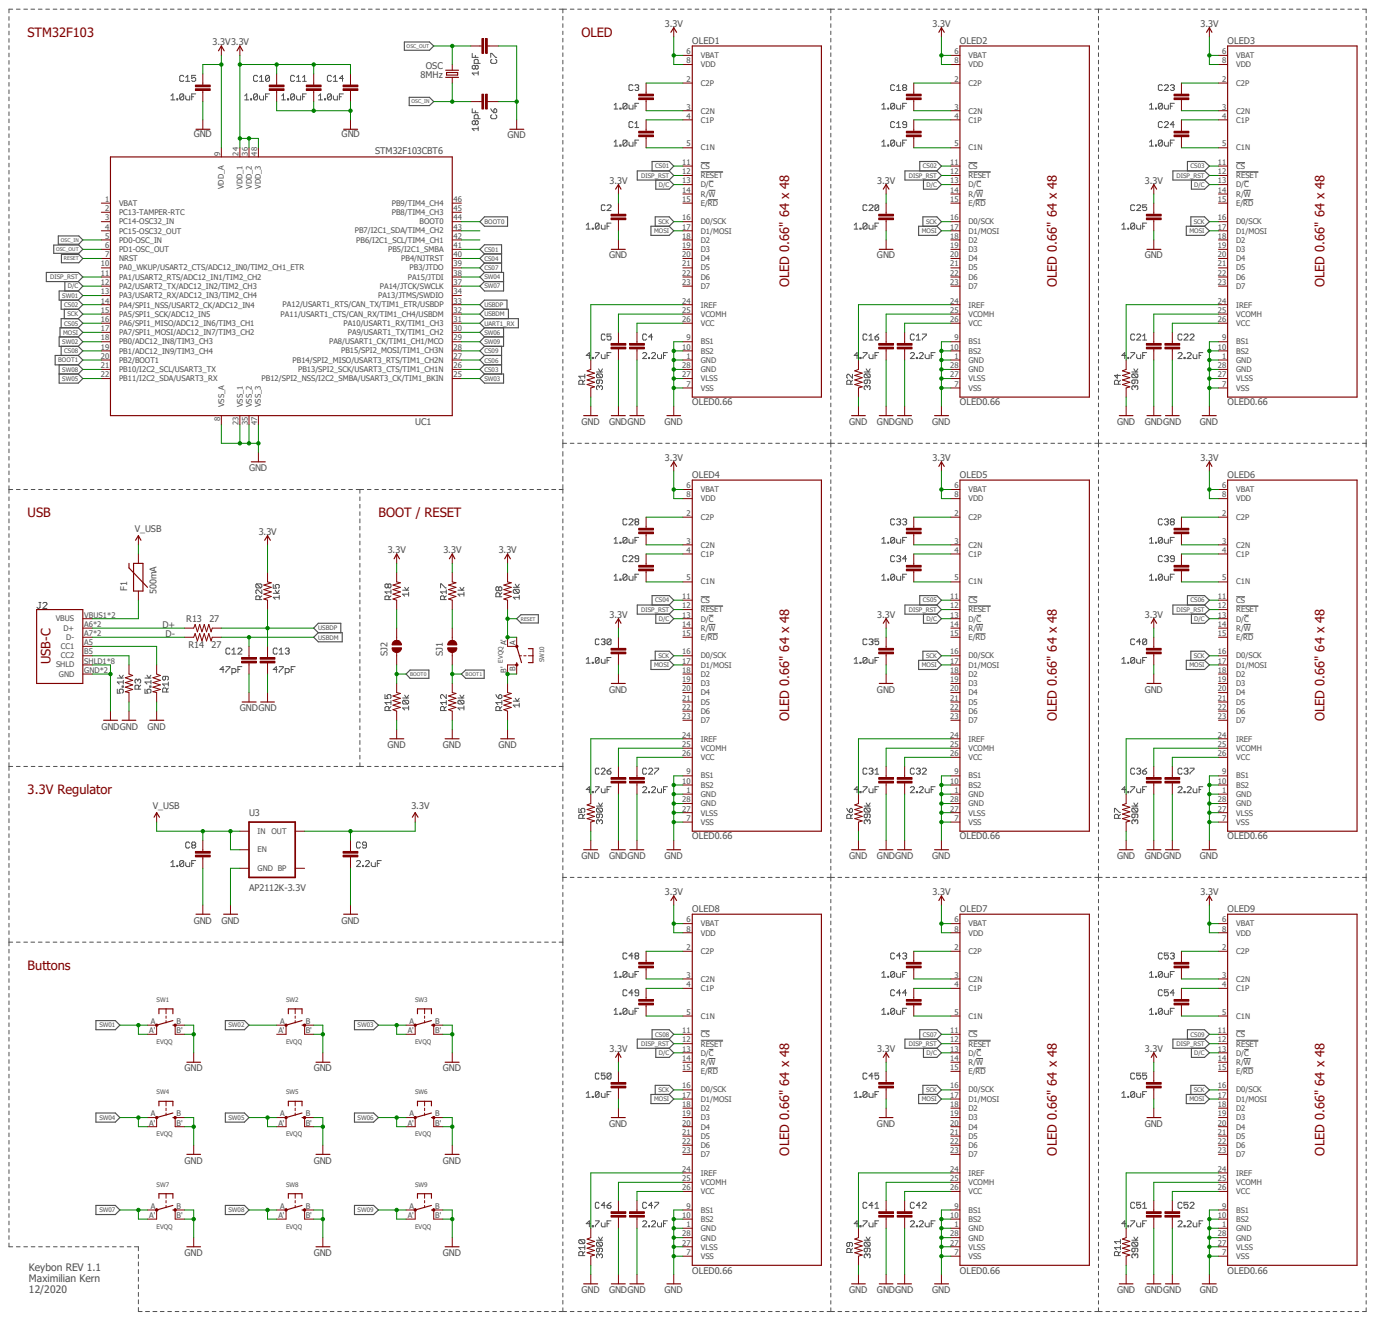
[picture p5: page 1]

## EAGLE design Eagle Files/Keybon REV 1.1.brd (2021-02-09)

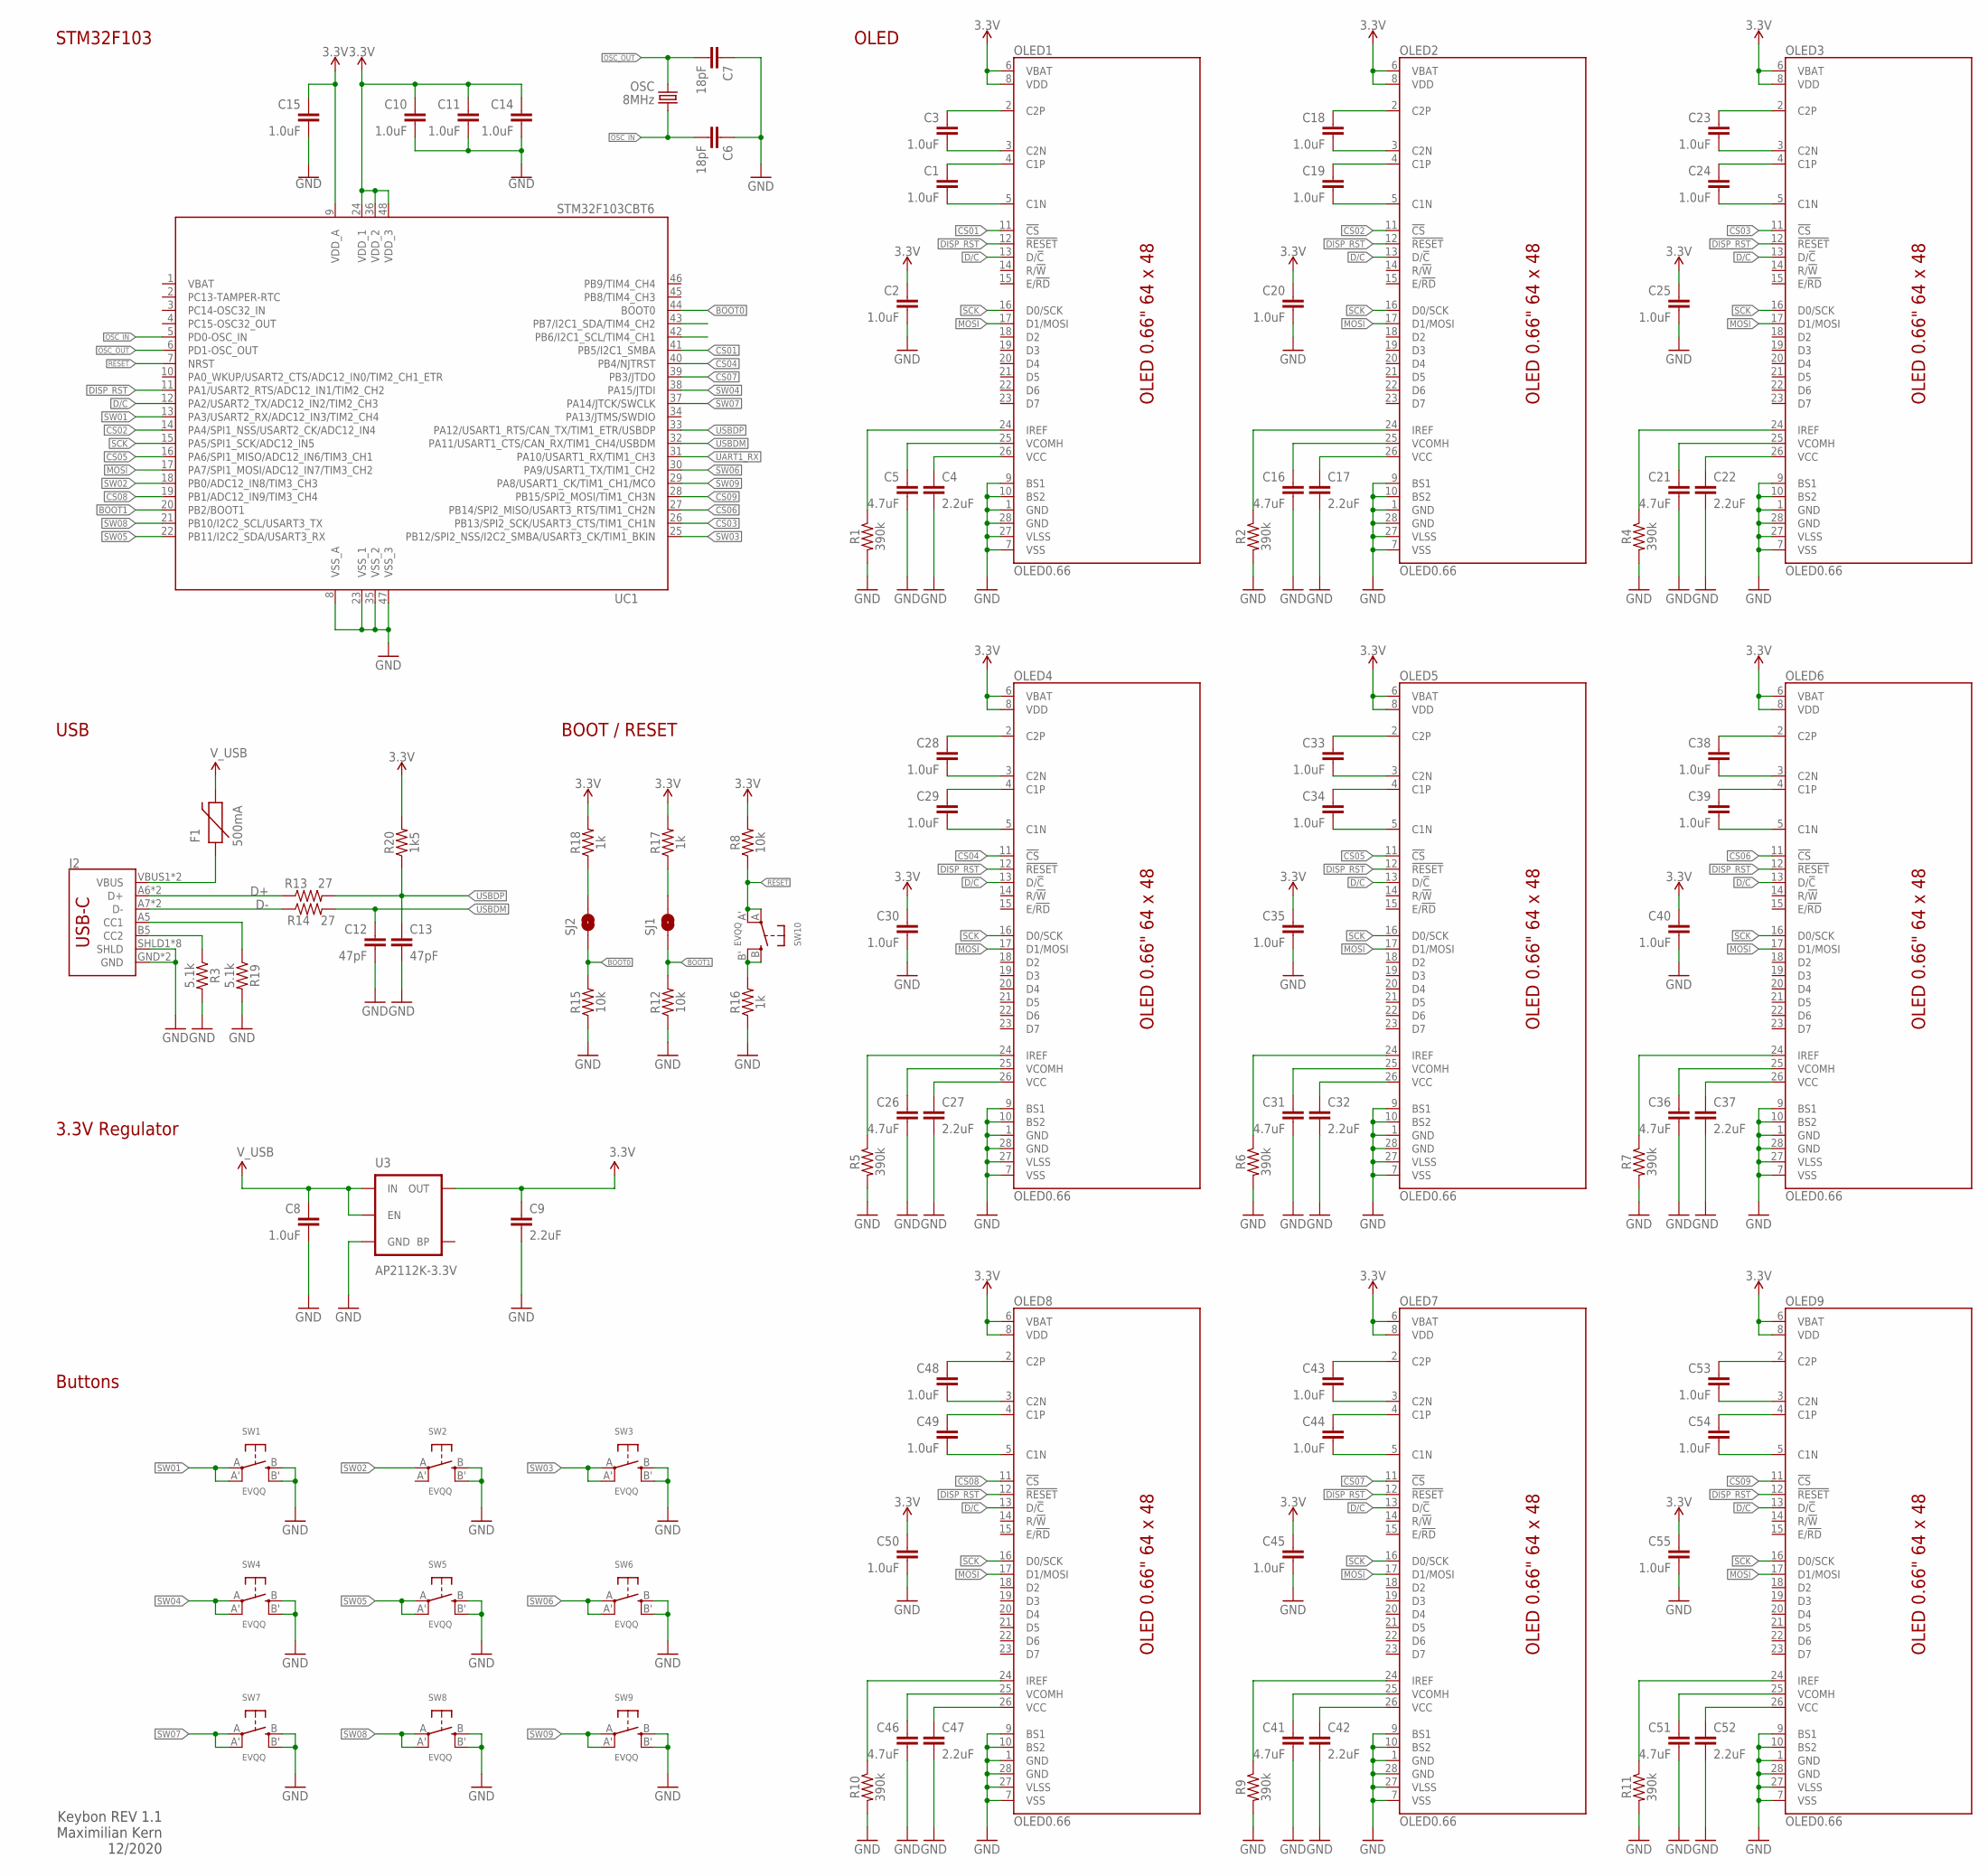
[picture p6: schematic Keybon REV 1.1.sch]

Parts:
C1, C2, C3, C8, C10, C11, C14, C15, C18, C19, C20, C23, C24, C25, C28, C29, C30, C33, C34, C35, C38, C39, C40, C43, C44, C45, C48, C49, C50, C53, C54, C55: 1.0uF; 0805
C4, C9, C17, C22, C27, C32, C37, C42, C47, C52: 2.2uF; 0805
C5, C16, C21, C26, C31, C36, C41, C46, C51: 4.7uF; 0603
C6, C7: 18pF; 0603
C12, C13: 47pF; 0603
F1: 500mA; PTC-1206
J2: USB_C16PIN; USB-C-16P
OLED1, OLED2, OLED3, OLED4, OLED5, OLED6, OLED7, OLED8, OLED9: OLED0.66; OLED-0.66-64X48
OSC: 8MHz; CRYSTAL-SMD-5X3
R1, R2, R4, R5, R6, R7, R9, R10, R11: 390k; 0603
R3, R19: 5.1k; 0603
R8, R12, R15: 10k; 0603
R13, R14: 27; 0603
R16, R17, R18: 1k; 0603
R20: 1k5; 0603
SJ1, SJ2: JUMPER-PAD-2-NOYES_SILK; PAD-JUMPER-2-NO_YES_SILK
SW1, SW2, SW3, SW4, SW5, SW6, SW7, SW8, SW9, SW10: EVQQ; EVQ-Q2_SMALLER
U3: AP2112K-3.3V; SOT23-5
UC1: STM32F103CBT6; LQFP48

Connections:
3.3V: C2.1, C9.1, C10.1, C11.1, C14.1, C15.1, C20.1, C25.1, C30.1, C35.1, C40.1, C45.1, C50.1, C55.1, OLED1.6 (VBAT), OLED1.8 (VDD), OLED2.6 (VBAT), OLED2.8 (VDD), OLED3.6 (VBAT), OLED3.8 (VDD), OLED4.6 (VBAT), OLED4.8 (VDD), OLED5.6 (VBAT), OLED5.8 (VDD), OLED6.6 (VBAT), OLED6.8 (VDD), OLED7.6 (VBAT), OLED7.8 (VDD), OLED8.6 (VBAT), OLED8.8 (VDD), OLED9.6 (VBAT), OLED9.8 (VDD), R8.2, R17.2, R18.2, R20.2, U3.5 (OUT), UC1.9 (VDD_A), UC1.24 (VDD_1), UC1.36 (VDD_2), UC1.48 (VDD_3)
BOOT0: R15.2, SJ2.1, UC1.44 (BOOT0)
BOOT1: R12.2, SJ1.1, UC1.20 (PB2/BOOT1)
C1N: C1.2, OLED1.5 (C1N)
C1N1: C19.2, OLED2.5 (C1N)
C1N2: C24.2, OLED3.5 (C1N)
C1N3: C29.2, OLED4.5 (C1N)
C1N4: C34.2, OLED5.5 (C1N)
C1N5: C39.2, OLED6.5 (C1N)
C1N6: C44.2, OLED7.5 (C1N)
C1N7: C49.2, OLED8.5 (C1N)
C1N8: C54.2, OLED9.5 (C1N)
C1P: C1.1, OLED1.4 (C1P)
C1P1: C19.1, OLED2.4 (C1P)
C1P2: C24.1, OLED3.4 (C1P)
C1P3: C29.1, OLED4.4 (C1P)
C1P4: C34.1, OLED5.4 (C1P)
C1P5: C39.1, OLED6.4 (C1P)
C1P6: C44.1, OLED7.4 (C1P)
C1P7: C49.1, OLED8.4 (C1P)
C1P8: C54.1, OLED9.4 (C1P)
C2N: C3.2, OLED1.3 (C2N)
C2N1: C18.2, OLED2.3 (C2N)
C2N2: C23.2, OLED3.3 (C2N)
C2N3: C28.2, OLED4.3 (C2N)
C2N4: C33.2, OLED5.3 (C2N)
C2N5: C38.2, OLED6.3 (C2N)
C2N6: C43.2, OLED7.3 (C2N)
C2N7: C48.2, OLED8.3 (C2N)
C2N8: C53.2, OLED9.3 (C2N)
C2P: C3.1, OLED1.2 (C2P)
C2P1: C18.1, OLED2.2 (C2P)
C2P2: C23.1, OLED3.2 (C2P)
C2P3: C28.1, OLED4.2 (C2P)
C2P4: C33.1, OLED5.2 (C2P)
C2P5: C38.1, OLED6.2 (C2P)
C2P6: C43.1, OLED7.2 (C2P)
C2P7: C48.1, OLED8.2 (C2P)
C2P8: C53.1, OLED9.2 (C2P)
CS01: OLED1.11 (!CS!), UC1.41 (PB5/I2C1_SMBA)
CS02: OLED2.11 (!CS!), UC1.14 (PA4/SPI1_NSS/USART2_CK/ADC12_IN4)
CS03: OLED3.11 (!CS!), UC1.26 (PB13/SPI2_SCK/USART3_CTS/TIM1_CH1N)
CS04: OLED4.11 (!CS!), UC1.40 (PB4/NJTRST)
CS05: OLED5.11 (!CS!), UC1.16 (PA6/SPI1_MISO/ADC12_IN6/TIM3_CH1)
CS06: OLED6.11 (!CS!), UC1.27 (PB14/SPI2_MISO/USART3_RTS/TIM1_CH2N)
CS07: OLED7.11 (!CS!), UC1.39 (PB3/JTDO)
CS08: OLED8.11 (!CS!), UC1.19 (PB1/ADC12_IN9/TIM3_CH4)
CS09: OLED9.11 (!CS!), UC1.28 (PB15/SPI2_MOSI/TIM1_CH3N)
D+: J2.A6 (D+), J2.B6 (D+), R13.1
D-: J2.A7 (D-), J2.B7 (D-), R14.1
D/C: OLED1.13 (D/!C!), OLED2.13 (D/!C!), OLED3.13 (D/!C!), OLED4.13 (D/!C!), OLED5.13 (D/!C!), OLED6.13 (D/!C!), OLED7.13 (D/!C!), OLED8.13 (D/!C!), OLED9.13 (D/!C!), UC1.12 (PA2/USART2_TX/ADC12_IN2/TIM2_CH3)
DISP_RST: OLED1.12 (!RESET!), OLED2.12 (!RESET!), OLED3.12 (!RESET!), OLED4.12 (!RESET!), OLED5.12 (!RESET!), OLED6.12 (!RESET!), OLED7.12 (!RESET!), OLED8.12 (!RESET!), OLED9.12 (!RESET!), UC1.11 (PA1/USART2_RTS/ADC12_IN1/TIM2_CH2)
GND: C2.2, C4.2, C5.2, C6.1, C7.1, C8.2, C9.2, C10.2, C11.2, C12.2, C13.2, C14.2, C15.2, C16.2, C17.2, C20.2, C21.2, C22.2, C25.2, C26.2, C27.2, C30.2, C31.2, C32.2, C35.2, C36.2, C37.2, C40.2, C41.2, C42.2, C45.2, C46.2, C47.2, C50.2, C51.2, C52.2, C55.2, J2.GND, J2.GND2 (GND), J2.SHLD1 (SHLD), J2.SHLD2 (SHLD), J2.SHLD3 (SHLD), J2.SHLD4 (SHLD), J2.SHLD5 (SHLD), J2.SHLD6 (SHLD), J2.SHLD7 (SHLD), J2.SHLD8 (SHLD), OLED1.1 (GND), OLED1.7 (VSS), OLED1.9 (BS1), OLED1.10 (BS2), OLED1.27 (VLSS), OLED1.28 (GND), OLED2.1 (GND), OLED2.7 (VSS), OLED2.9 (BS1), OLED2.10 (BS2), OLED2.27 (VLSS), OLED2.28 (GND), OLED3.1 (GND), OLED3.7 (VSS), OLED3.9 (BS1), OLED3.10 (BS2), OLED3.27 (VLSS), OLED3.28 (GND), OLED4.1 (GND), OLED4.7 (VSS), OLED4.9 (BS1), OLED4.10 (BS2), OLED4.27 (VLSS), OLED4.28 (GND), OLED5.1 (GND), OLED5.7 (VSS), OLED5.9 (BS1), OLED5.10 (BS2), OLED5.27 (VLSS), OLED5.28 (GND), OLED6.1 (GND), OLED6.7 (VSS), OLED6.9 (BS1), OLED6.10 (BS2), OLED6.27 (VLSS), OLED6.28 (GND), OLED7.1 (GND), OLED7.7 (VSS), OLED7.9 (BS1), OLED7.10 (BS2), OLED7.27 (VLSS), OLED7.28 (GND), OLED8.1 (GND), OLED8.7 (VSS), OLED8.9 (BS1), OLED8.10 (BS2), OLED8.27 (VLSS), OLED8.28 (GND), OLED9.1 (GND), OLED9.7 (VSS), OLED9.9 (BS1), OLED9.10 (BS2), OLED9.27 (VLSS), OLED9.28 (GND), R1.2, R2.2, R3.2, R4.2, R5.2, R6.2, R7.2, R9.2, R10.2, R11.2, R12.1, R15.1, R16.1, R19.2, SW1.B (S), SW1.B' (S1), SW2.B (S), SW2.B' (S1), SW3.B (S), SW3.B' (S1), SW4.B (S), SW4.B' (S1), SW5.B (S), SW5.B' (S1), SW6.B (S), SW6.B' (S1), SW7.B (S), SW7.B' (S1), SW8.B (S), SW8.B' (S1), SW9.B (S), SW9.B' (S1), U3.2 (GND), UC1.8 (VSS_A), UC1.23 (VSS_1), UC1.35 (VSS_2), UC1.47 (VSS_3)
IREF: OLED1.24 (IREF), R1.1
IREF1: OLED2.24 (IREF), R2.1
IREF2: OLED3.24 (IREF), R4.1
IREF3: OLED4.24 (IREF), R5.1
IREF4: OLED5.24 (IREF), R6.1
IREF5: OLED6.24 (IREF), R7.1
IREF6: OLED7.24 (IREF), R9.1
IREF7: OLED8.24 (IREF), R10.1
IREF8: OLED9.24 (IREF), R11.1
MOSI: OLED1.17 (D1/MOSI), OLED2.17 (D1/MOSI), OLED3.17 (D1/MOSI), OLED4.17 (D1/MOSI), OLED5.17 (D1/MOSI), OLED6.17 (D1/MOSI), OLED7.17 (D1/MOSI), OLED8.17 (D1/MOSI), OLED9.17 (D1/MOSI), UC1.17 (PA7/SPI1_MOSI/ADC12_IN7/TIM3_CH2)
unnamed: R16.2, SW10.B (S), SW10.B' (S1)
unnamed: R18.1, SJ2.2
unnamed: R17.1, SJ1.2
unnamed: C4.1, OLED1.26 (VCC)
unnamed: C17.1, OLED2.26 (VCC)
unnamed: C22.1, OLED3.26 (VCC)
unnamed: C37.1, OLED6.26 (VCC)
unnamed: C32.1, OLED5.26 (VCC)
unnamed: J2.A5 (CC1), R19.1
unnamed: C27.1, OLED4.26 (VCC)
unnamed: J2.B5 (CC2), R3.1
unnamed: C47.1, OLED8.26 (VCC)
unnamed: C42.1, OLED7.26 (VCC)
unnamed: C52.1, OLED9.26 (VCC)
OSC_IN: C6.2, OSC.1, UC1.5 (PD0-OSC_IN)
OSC_OUT: C7.2, OSC.3 (2), UC1.6 (PD1-OSC_OUT)
RESET: R8.1, SW10.A, SW10.A' (P1), UC1.7 (NRST)
SCK: OLED1.16 (D0/SCK), OLED2.16 (D0/SCK), OLED3.16 (D0/SCK), OLED4.16 (D0/SCK), OLED5.16 (D0/SCK), OLED6.16 (D0/SCK), OLED7.16 (D0/SCK), OLED8.16 (D0/SCK), OLED9.16 (D0/SCK), UC1.15 (PA5/SPI1_SCK/ADC12_IN5)
SW01: SW1.A, SW1.A' (P1), UC1.13 (PA3/USART2_RX/ADC12_IN3/TIM2_CH4)
SW02: SW2.A, UC1.18 (PB0/ADC12_IN8/TIM3_CH3)
SW03: SW3.A, SW3.A' (P1), UC1.25 (PB12/SPI2_NSS/I2C2_SMBA/USART3_CK/TIM1_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)
SW04: SW4.A, SW4.A' (P1), UC1.38 (PA15/JTDI)
SW05: SW5.A, SW5.A' (P1), UC1.22 (PB11/I2C2_SDA/USART3_RX)
SW06: SW6.A, SW6.A' (P1), UC1.30 (PA9/USART1_TX/TIM1_CH2)
SW07: SW7.A, SW7.A' (P1), UC1.37 (PA14/JTCK/SWCLK)
SW08: SW8.A, SW8.A' (P1), UC1.21 (PB10/I2C2_SCL/USART3_TX)
SW09: SW9.A, SW9.A' (P1), UC1.29 (PA8/USART1_CK/TIM1_CH1/MCO)
UART1_RX: UC1.31 (PA10/USART1_RX/TIM1_CH3)
USBDM: C12.1, R14.2, UC1.32 (PA11/USART1_CTS/CAN_RX/TIM1_CH4/USBDM)
USBDP: C13.1, R13.2, R20.1, UC1.33 (PA12/USART1_RTS/CAN_TX/TIM1_ETR/USBDP)
VBAT: UC1.1 (VBAT)
VCOMH: C5.1, OLED1.25 (VCOMH)
VCOMH1: C16.1, OLED2.25 (VCOMH)
VCOMH2: C21.1, OLED3.25 (VCOMH)
VCOMH3: C26.1, OLED4.25 (VCOMH)
VCOMH4: C31.1, OLED5.25 (VCOMH)
VCOMH5: C36.1, OLED6.25 (VCOMH)
VCOMH6: C41.1, OLED7.25 (VCOMH)
VCOMH7: C46.1, OLED8.25 (VCOMH)
VCOMH8: C51.1, OLED9.25 (VCOMH)
VUSB-RAW: F1.1, J2.VBUS1 (VBUS), J2.VBUS2 (VBUS)
V_USB: C8.1, F1.2, U3.1 (IN), U3.3 (EN)

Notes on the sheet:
Buttons
OLED
STM32F103
USB
BOOT / RESET
3.3V Regulator
Keybon REV 1.1 Maximilian Kern 12/2020

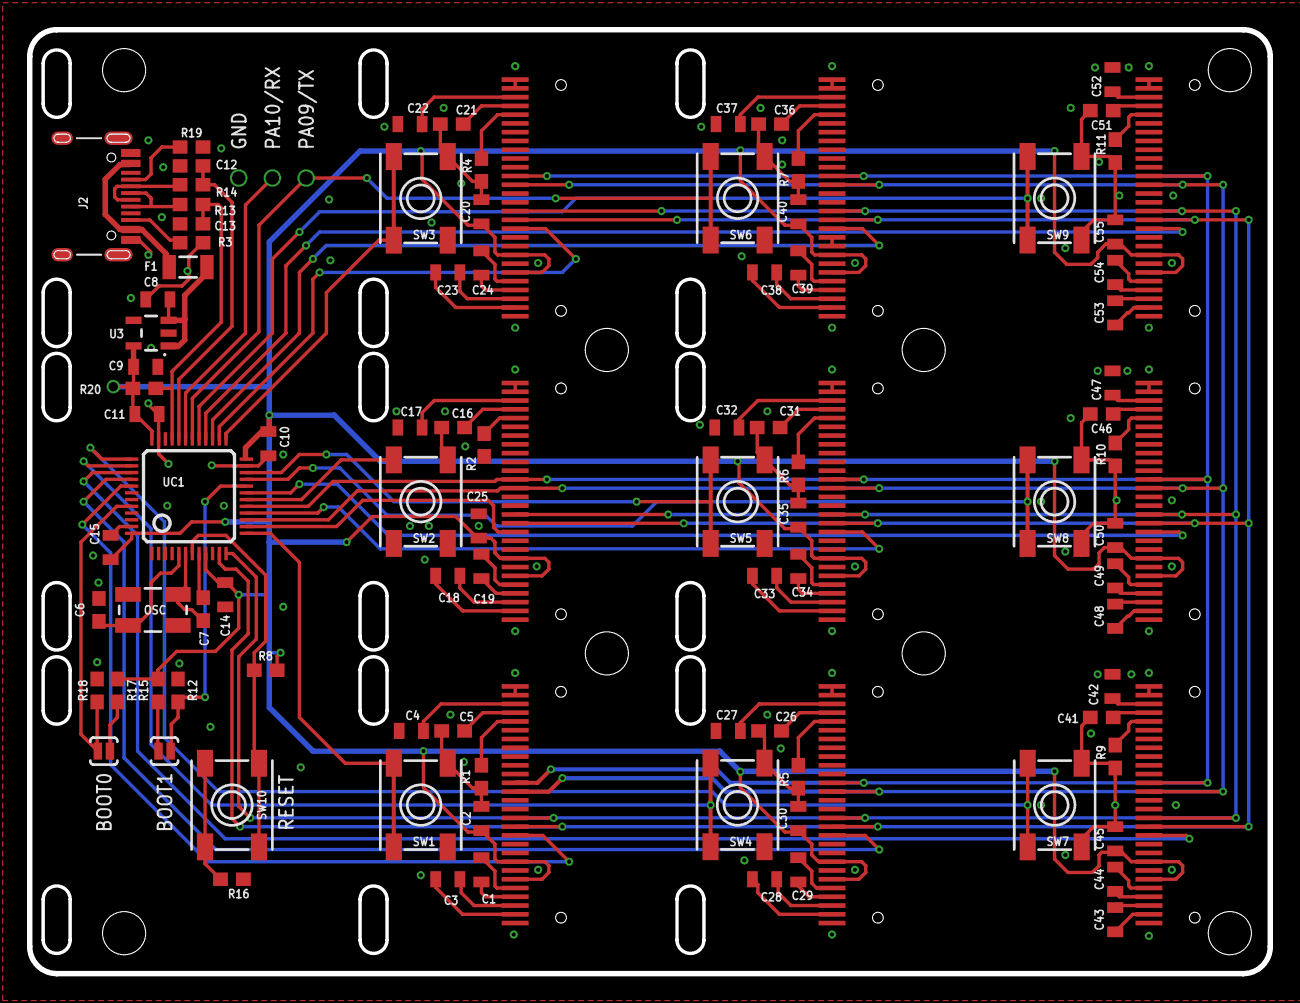
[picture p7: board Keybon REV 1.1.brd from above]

Board: 2 copper layers, 92.0 x 70.0 mm, 101 parts (0 on the bottom side), 103 nets.

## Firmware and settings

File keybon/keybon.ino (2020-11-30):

#include <USBComposite.h>
#include <SPI.h>
#include <Wire.h>
#include <Adafruit_GFX.h>
#include <Adafruit_SSD1306.h>
#include <Button.h> // https://github.com/JChristensen/Button
#include "bmp.h"

USBHID HID;
HIDKeyboard Keyboard(HID);
HIDConsumer Consumer(HID);
USBCompositeSerial CompositeSerial;


#define PRODUCT_ID 0x29

#define SW01 PA3
#define SW02 PB0
#define SW03 PB12
#define SW04 PA15
#define SW05 PB11
#define SW06 PA9
#define SW07 PA14
#define SW08 PB10
#define SW09 PA8

#define OLED_MOSI  PA7
#define OLED_CLK   PA5
#define OLED_DC    PA2
#define OLED_CS01    PB5
#define OLED_CS02    PA4
#define OLED_CS03    PB13
#define OLED_CS04    PB4
#define OLED_CS05    PA6
#define OLED_CS06    PB14
#define OLED_CS07    PB3
#define OLED_CS08    PB1
#define OLED_CS09    PB15
#define OLED_RESET PA1

Adafruit_SSD1306 OLED01(128, 48, OLED_MOSI, OLED_CLK, OLED_DC, OLED_RESET, OLED_CS01);
Adafruit_SSD1306 OLED02(128, 48, OLED_MOSI, OLED_CLK, OLED_DC, OLED_RESET, OLED_CS02);
Adafruit_SSD1306 OLED03(128, 48, OLED_MOSI, OLED_CLK, OLED_DC, OLED_RESET, OLED_CS03);
Adafruit_SSD1306 OLED04(128, 48, OLED_MOSI, OLED_CLK, OLED_DC, OLED_RESET, OLED_CS04);
Adafruit_SSD1306 OLED05(128, 48, OLED_MOSI, OLED_CLK, OLED_DC, OLED_RESET, OLED_CS05);
Adafruit_SSD1306 OLED06(128, 48, OLED_MOSI, OLED_CLK, OLED_DC, OLED_RESET, OLED_CS06);
Adafruit_SSD1306 OLED07(128, 48, OLED_MOSI, OLED_CLK, OLED_DC, OLED_RESET, OLED_CS07);
Adafruit_SSD1306 OLED08(128, 48, OLED_MOSI, OLED_CLK, OLED_DC, OLED_RESET, OLED_CS08);
Adafruit_SSD1306 OLED09(128, 48, OLED_MOSI, OLED_CLK, OLED_DC, OLED_RESET, OLED_CS09);

Button button01(SW01, true, true, 5); //pin, pullup, invert, debounce
Button button02(SW02, true, true, 5); //pin, pullup, invert, debounce
Button button03(SW03, true, true, 5); //pin, pullup, invert, debounce
Button button04(SW04, true, true, 5); //pin, pullup, invert, debounce
Button button05(SW05, true, true, 5); //pin, pullup, invert, debounce
Button button06(SW06, true, true, 5); //pin, pullup, invert, debounce
Button button07(SW07, true, true, 5); //pin, pullup, invert, debounce
Button button08(SW08, true, true, 5); //pin, pullup, invert, debounce
Button button09(SW09, true, true, 5); //pin, pullup, invert, debounce

unsigned int cursor = 0;

boolean defaultLayoutActive = true;


void setup() {
  pinMode(SW01, INPUT_PULLUP);
  pinMode(SW02, INPUT_PULLUP);
  pinMode(SW03, INPUT_PULLUP);
  pinMode(SW04, INPUT_PULLUP);
  pinMode(SW05, INPUT_PULLUP);
  pinMode(SW06, INPUT_PULLUP);
  pinMode(SW07, INPUT_PULLUP);
  pinMode(SW08, INPUT_PULLUP);
  pinMode(SW09, INPUT_PULLUP);
  
  USBComposite.setProductId(PRODUCT_ID);
  HID.registerComponent();
  CompositeSerial.registerComponent();
  USBComposite.begin();

  OLED01.begin(SSD1306_SWITCHCAPVCC, 0, true, true); // OLEDs share same reset line, o
  OLED01.setRotation(0);
  OLED02.begin(SSD1306_SWITCHCAPVCC, 0, false, true);
  OLED02.setRotation(0);
  OLED03.begin(SSD1306_SWITCHCAPVCC, 0, false, true);
  OLED03.setRotation(0);
  OLED04.begin(SSD1306_SWITCHCAPVCC, 0, false, true);
  OLED04.setRotation(0);
  OLED05.begin(SSD1306_SWITCHCAPVCC, 0, false, true);
  OLED05.setRotation(0);
  OLED06.begin(SSD1306_SWITCHCAPVCC, 0, false, true);
  OLED06.setRotation(0);
  OLED07.begin(SSD1306_SWITCHCAPVCC, 0, false, true);
  OLED07.setRotation(0);
  OLED08.begin(SSD1306_SWITCHCAPVCC, 0, false, true);
  OLED08.setRotation(0);
  OLED09.begin(SSD1306_SWITCHCAPVCC, 0, false, true);
  OLED09.setRotation(0);

  displayContrast(LOW);
  
  OLED01.clearDisplay();   // clears the screen and buffer
  OLED02.clearDisplay();
  OLED03.clearDisplay();
  OLED04.clearDisplay();
  OLED05.clearDisplay();
  OLED06.clearDisplay();
  OLED07.clearDisplay();
  OLED08.clearDisplay();
  OLED09.clearDisplay();
  
  //delay(500);
  CompositeSerial.setTimeout(200);

  OLED01.drawBitmap(32, 0, bmp_mute, 64, 48, WHITE);
  OLED02.drawBitmap(32, 0, bmp_volume_down, 64, 48, WHITE);
  OLED03.drawBitmap(32, 0, bmp_volume_up, 64, 48, WHITE);
  OLED04.drawBitmap(32, 0, bmp_backward, 64, 48, WHITE);
  OLED05.drawBitmap(32, 0, bmp_play, 64, 48, WHITE);
  OLED06.drawBitmap(32, 0, bmp_forward, 64, 48, WHITE);
  OLED07.drawBitmap(32, 0, bmp_explorer, 64, 48, WHITE);
  OLED08.drawBitmap(32, 0, bmp_snapshot, 64, 48, WHITE);
  OLED09.drawBitmap(32, 0, bmp_calc, 64, 48, WHITE);
}

void loop() {

  if(button01.wasPressed() or button01.pressedFor(300)){
    if(defaultLayoutActive){
      Consumer.press(HIDConsumer::MUTE);
      Consumer.release();
    }
    else CompositeSerial.print("1");
  }
  if(button02.wasPressed() or button02.pressedFor(300)){
    if(defaultLayoutActive){
      Consumer.press(HIDConsumer::VOLUME_DOWN);
      Consumer.release();
    }
    else CompositeSerial.print("2");
  }
  if(button03.wasPressed() or button03.pressedFor(300)){
    if(defaultLayoutActive){
      Consumer.press(HIDConsumer::VOLUME_UP);
      Consumer.release();
    }
    else CompositeSerial.print("3");
  }
  if(button04.wasPressed() or button04.pressedFor(300)){
    if(defaultLayoutActive){
      Consumer.press(182);
      Consumer.release();
    }
    else CompositeSerial.print("4");
  }
  if(button05.wasPressed() or button05.pressedFor(300)){
    if(defaultLayoutActive){
      Consumer.press(HIDConsumer::PLAY_OR_PAUSE);
      Consumer.release();
    }
    else CompositeSerial.print("5");
  }
  if(button06.wasPressed() or button06.pressedFor(300)){
    if(defaultLayoutActive){
      Consumer.press(181);
      Consumer.release();
    }
    else CompositeSerial.print("6");
  }
  if(button07.wasPressed() or button07.pressedFor(300)){
    if(defaultLayoutActive){
      Keyboard.press(KEY_LEFT_GUI);
      Keyboard.press('e');
      Keyboard.release('e');
      Keyboard.release(KEY_LEFT_GUI);
    }
    else CompositeSerial.print("7");
  }
  if(button08.wasPressed() or button08.pressedFor(300)){
    if(defaultLayoutActive){
      Keyboard.press(KEY_LEFT_GUI);
      Keyboard.press(KEY_LEFT_SHIFT);
      Keyboard.press('s');
      Keyboard.release('s');
      Keyboard.release(KEY_LEFT_SHIFT);
      Keyboard.release(KEY_LEFT_GUI);
    }
    else CompositeSerial.print("8");
  }
  if(button09.wasPressed() or button09.pressedFor(300)){
    if(defaultLayoutActive){
      Keyboard.press(KEY_LEFT_GUI);
      Keyboard.press('r');
      Keyboard.release('r');
      Keyboard.release(KEY_LEFT_GUI);
      Keyboard.print("calc");
      Keyboard.press('\n');
      Keyboard.release('\n');
    }
    else CompositeSerial.print("9");
  }

  
  while (CompositeSerial.available() > 0){
    byte command = CompositeSerial.read();
    if(command >= '0' && command <= '8'){
      defaultLayoutActive = false;
      CompositeSerial.readBytes(bmp_swap,384);
      if(command == '0'){
        OLED01.clearDisplay();
        OLED01.drawBitmap(32, 0, bmp_swap, 64, 48, WHITE);
      }
      if(command == '1'){
        OLED02.clearDisplay();
        OLED02.drawBitmap(32, 0, bmp_swap, 64, 48, WHITE);
      }
      if(command == '2'){
        OLED03.clearDisplay();
        OLED03.drawBitmap(32, 0, bmp_swap, 64, 48, WHITE);
      }
      if(command == '3'){
        OLED04.clearDisplay();
        OLED04.drawBitmap(32, 0, bmp_swap, 64, 48, WHITE);
      }
      if(command == '4'){
        OLED05.clearDisplay();
        OLED05.drawBitmap(32, 0, bmp_swap, 64, 48, WHITE);
      }
      if(command == '5'){
        OLED06.clearDisplay();
        OLED06.drawBitmap(32, 0, bmp_swap, 64, 48, WHITE);
      }
      if(command == '6'){
        OLED07.clearDisplay();
        OLED07.drawBitmap(32, 0, bmp_swap, 64, 48, WHITE);
      }
      if(command == '7'){
        OLED08.clearDisplay();
        OLED08.drawBitmap(32, 0, bmp_swap, 64, 48, WHITE);
      }
      if(command == '8'){
        OLED09.clearDisplay();
        OLED09.drawBitmap(32, 0, bmp_swap, 64, 48, WHITE);
      }
    }
    else if(command == 'D'){ //fallback to internal Layout
      defaultLayoutActive = true;
      OLED01.clearDisplay();   // clears the screen and buffer
      OLED02.clearDisplay();
      OLED03.clearDisplay();
      OLED04.clearDisplay();
      OLED05.clearDisplay();
      OLED06.clearDisplay();
      OLED07.clearDisplay();
      OLED08.clearDisplay();
      OLED09.clearDisplay();
      OLED01.drawBitmap(32, 0, bmp_mute, 64, 48, WHITE);
      OLED02.drawBitmap(32, 0, bmp_volume_down, 64, 48, WHITE);
      OLED03.drawBitmap(32, 0, bmp_volume_up, 64, 48, WHITE);
      OLED04.drawBitmap(32, 0, bmp_backward, 64, 48, WHITE);
      OLED05.drawBitmap(32, 0, bmp_play, 64, 48, WHITE);
      OLED06.drawBitmap(32, 0, bmp_forward, 64, 48, WHITE);
      OLED07.drawBitmap(32, 0, bmp_explorer, 64, 48, WHITE);
      OLED08.drawBitmap(32, 0, bmp_snapshot, 64, 48, WHITE);
      OLED09.drawBitmap(32, 0, bmp_calc, 64, 48, WHITE);
    }
    else if(command == 'A'){ //Answer to call
      CompositeSerial.print("a");
    }
    else if(command == 'B'){ //high brightness
      displayContrast(HIGH);
    }
    else if(command == 'b'){ //low brightness
      displayContrast(LOW);
    }
  }
  
  //OLED09.setCursor(32, 10);
  //OLED09.setTextColor(WHITE);
  //OLED09.setTextSize(1);
  //OLED09.print(cursor);

  OLED01.display();
  OLED02.display();
  OLED03.display();
  OLED04.display();
  OLED05.display();
  OLED06.display();
  OLED07.display();
  OLED08.display();
  OLED09.display();

  button01.read();
  button02.read();
  button03.read();
  button04.read();
  button05.read();
  button06.read();
  button07.read();
  button08.read();
  button09.read();

}

void displayContrast(boolean contrast){
  byte contrastSetting = 0x35;
  if(contrast == HIGH) contrastSetting = 0x7F;
  
  OLED01.ssd1306_command(SSD1306_SETCONTRAST);
  OLED01.ssd1306_command(contrastSetting);
  OLED02.ssd1306_command(SSD1306_SETCONTRAST);
  OLED02.ssd1306_command(contrastSetting);
  OLED03.ssd1306_command(SSD1306_SETCONTRAST);
  OLED03.ssd1306_command(contrastSetting);
  OLED04.ssd1306_command(SSD1306_SETCONTRAST);
  OLED04.ssd1306_command(contrastSetting);
  OLED05.ssd1306_command(SSD1306_SETCONTRAST);
  OLED05.ssd1306_command(contrastSetting);
  OLED06.ssd1306_command(SSD1306_SETCONTRAST);
  OLED06.ssd1306_command(contrastSetting);
  OLED07.ssd1306_command(SSD1306_SETCONTRAST);
  OLED07.ssd1306_command(contrastSetting);
  OLED08.ssd1306_command(SSD1306_SETCONTRAST);
  OLED08.ssd1306_command(contrastSetting);
  OLED09.ssd1306_command(SSD1306_SETCONTRAST);
  OLED09.ssd1306_command(contrastSetting);
}

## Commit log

2020-12-05 Quicker Layout Switching
    Replaced GetPixel so Layout icons load much faster
2020-12-18 BOM added
    [Keybon REV 1.1 BOM.csv]
2021-02-09 bad silkscreen placement fixed
    [Keybon REV 1.1.brd]
2022-07-14 Gerber RS274X files added

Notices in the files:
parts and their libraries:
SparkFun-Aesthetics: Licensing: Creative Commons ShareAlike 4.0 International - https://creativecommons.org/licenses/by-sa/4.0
